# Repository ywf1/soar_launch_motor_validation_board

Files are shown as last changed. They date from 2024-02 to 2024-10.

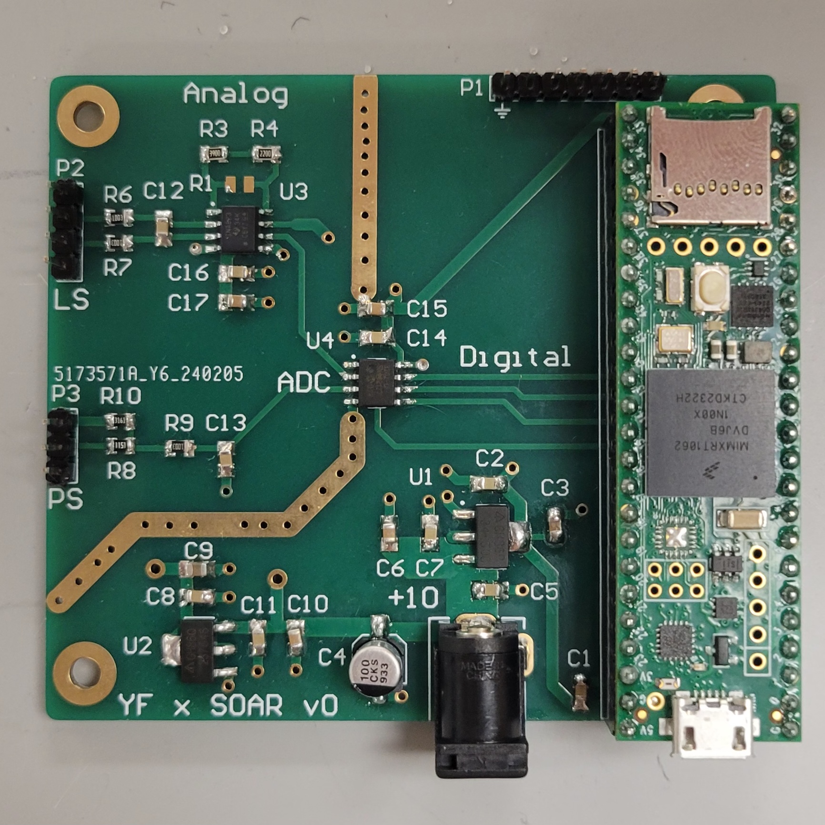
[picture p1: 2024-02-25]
flics/20240222_174141.jpg

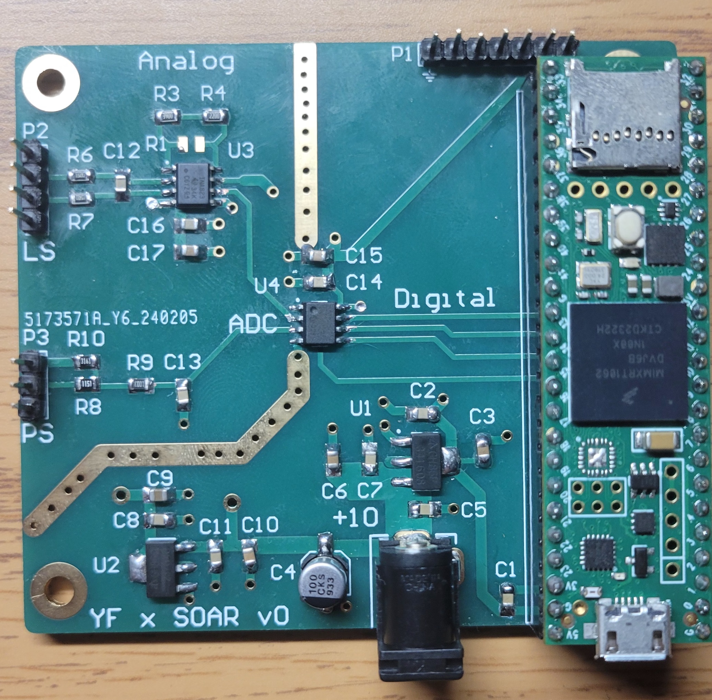
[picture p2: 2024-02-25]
flics/20240224_214641.jpg

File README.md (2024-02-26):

# soar_launch_motor_validation_board
PCB and Arduino Code for a data logging board for collecting data on solid rocket force and pressure output, along with GPIO for triggering ignition and testing

Sensor Inputs:
-  Load Cell
-  Pressure Sensor

[Load Cell](https://www.tgloadcells.com/products/tjh-4a-pancake-load-cell/):
-  +10V excitation
-  20mV @ max Load (1000 N)

[Pressure Sensor](https://www.rocketmotorparts.com/details/p1577809_21906261.aspx):
-  0 - 1600 PSI input
-  .5V - 4.5V voltage output

Board specs:
-  [Teensy 4.1 MCU](https://www.pjrc.com/store/teensy41.html)
-  [INA823 Instrumental Amplifier](https://www.ti.com/product/INA823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)
-  [MCP3202T 12-bit, 2 Channel, 50ksps](https://www.microchip.com/en-us/product/mcp3202)
-  Dual 3.3V, 5V LDO power bus
-  Accessible GPIO
  
Schematic:


Picture:


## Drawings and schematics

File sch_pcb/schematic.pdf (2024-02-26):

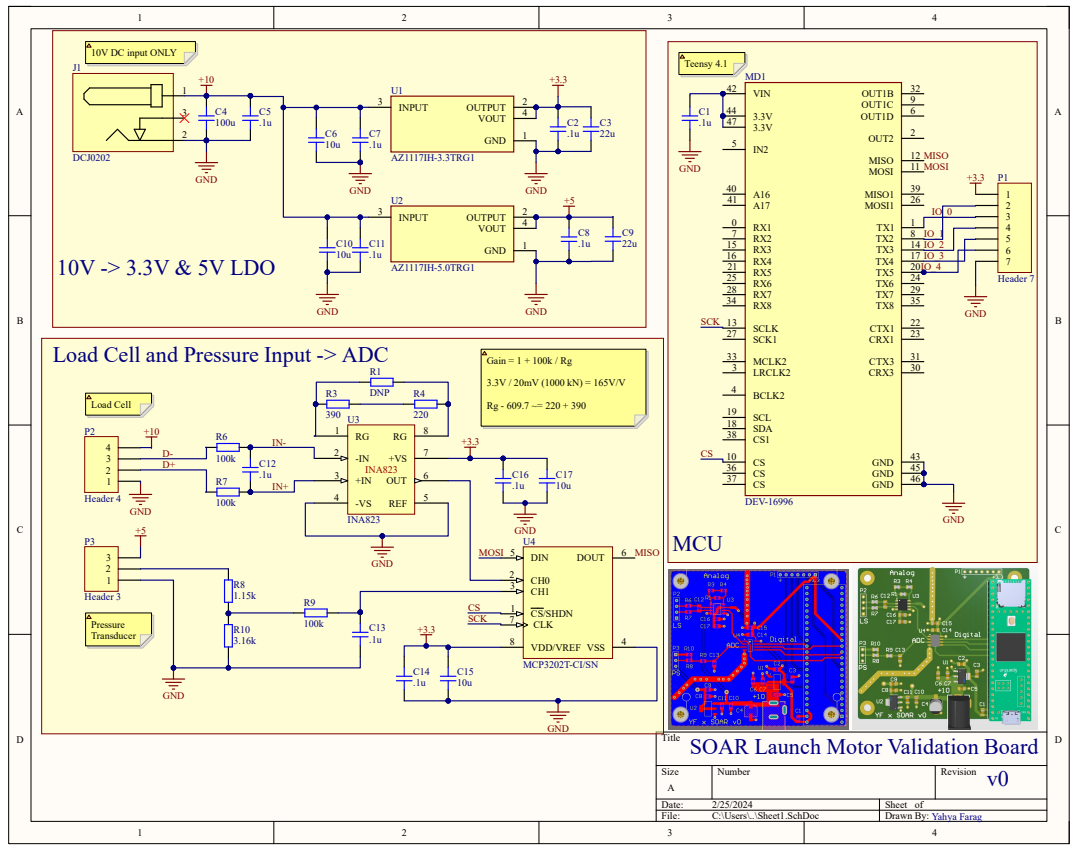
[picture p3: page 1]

Load Cell and Pressure Input -> ADC

Title
SOAR Launch Motor Validation Board

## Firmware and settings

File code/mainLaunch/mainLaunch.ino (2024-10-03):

#include <SPI.h>
#include <MCP3202.h>
#include <SD.h>
//these are dummy values rn
#define relayPin 8
#define beginLaunchPin 17
#define endParsingPin 14
#define LED 33

elapsedMicros timeStamp;

File dataFile;
// Variables will change:
volatile bool startParsing = false;
volatile bool fire = false;
volatile bool launchOver = false;

const double Vdd = 3.3; //Vdd

// Generally, you should use "unsigned long" for variables that hold time
// The value will quickly become too large for an int to store
unsigned long previousMillis = 0;  // will store last time LED was updated

MCP3202 adc = MCP3202(10); //Parameter passed is the CS pin number. Change according to requirement.

int pressureV = 0;
int forceV = 0;

long dummyCounter = 0;

void setup() {
  adc.begin();
  Serial.begin(115200);

  //I/O
  pinMode(relayPin, OUTPUT);
  digitalWrite(relayPin, LOW);
  pinMode(LED, OUTPUT);
  digitalWrite(LED, LOW);

  //begin launch input and interrupt
  pinMode(beginLaunchPin, INPUT_PULLDOWN);
  attachInterrupt(digitalPinToInterrupt(beginLaunchPin), beginLaunch, HIGH);

  //begin stop launch input and interrupt
  pinMode(endParsingPin, INPUT_PULLDOWN);
  attachInterrupt(digitalPinToInterrupt(endParsingPin), endParsing, HIGH);
  
  //SD setup
  if (!SD.begin(BUILTIN_SDCARD)) {
    Serial.println("Card failed, or not present");
    while (1) {
      // No SD card, so don't do anything more - stay stuck here
    }
  }
  dataFile = SD.open("3_31_0.txt", FILE_WRITE);
  if (dataFile) {
      Serial.println("SD Card File Found and Created");
      dataFile.println("Time(us),ForceRaw,PressureRaw,RelayValue");
    } 
}

void loop() {
  if(startParsing && !launchOver){
    if(timeStamp >= 1000000){
      fire = true;
      digitalWrite(relayPin, HIGH);
      if(timeStamp >= 2000000){
        digitalWrite(relayPin,LOW);
        fire = false;
      }
    }
    if (dataFile) {
      //log timestamp, pressure adc reading, and force adc readings
      pressureV = adc.readChannel(0);
      forceV = adc.readChannel(1);
      dataFile.print(timeStamp);
      dataFile.print(",");
      dataFile.print(pressureV);
      dataFile.print(",");
      dataFile.print(forceV);
      dataFile.print(",");
      dataFile.println(fire);
      //Serial.println(dummyCounter);
      //dummyCounter++;
    }
    if(timeStamp >= 20000000){
      startParsing = false;
      launchOver = true;
      dataFile.close();
    }
  } else if(launchOver){
    dataFile.close();
    digitalWrite(LED,HIGH);
    Serial.println("LaunchOver");
    digitalWrite(LED,HIGH);
    delay(500);
    digitalWrite(LED,LOW);
    delay(500);
  } else{
    //Serial.println("Awaiting launch..."); delay(100);
  }
}

void beginLaunch(){
  startParsing = true;
  timeStamp = 0;
  detachInterrupt(digitalPinToInterrupt(beginLaunchPin));
}

void endParsing(){
  if(startParsing){
    startParsing = false;
    launchOver = true;
    dataFile.close();
  }
}

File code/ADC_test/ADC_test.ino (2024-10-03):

#include <SPI.h>
#include <MCP3202.h>

const int ledPin = 33;  // the number of the LED pin

// Variables will change:
int ledState = LOW;  // ledState used to set the LED

// Generally, you should use "unsigned long" for variables that hold time
// The value will quickly become too large for an int to store
unsigned long previousMillis = 0;  // will store last time LED was updated

// constants won't change:
const long interval = 1000;  // interval at which to blink (milliseconds)

float Vdd = 3.3; //change according to your Vdd value.

MCP3202 adc = MCP3202(10); //Parameter passed is the CS pin number. Change according to requirement.

float channel0 = 0;
float channel1 = 0;
void setup() {
  // put your setup code here, to run once:
  adc.begin();
  Serial.begin(115200);
  pinMode(ledPin, OUTPUT);
}

void loop() {
  // put your main code here, to run repeatedly:
  channel0 = adc.readChannel(0);
  channel1 = adc.readChannel(1);
  //Serial.print(channel0);
  //Serial.print("channel 0 \t");

  //Serial.println(channel0);

  Serial.println(1.0*channel0*Vdd/4096.0);
  Serial.println(1.0*channel1*Vdd/4096.0);


  unsigned long currentMillis = millis();

  if (currentMillis - previousMillis >= interval) {
    // save the last time you blinked the LED
    previousMillis = currentMillis;

    // if the LED is off turn it on and vice-versa:
    if (ledState == LOW) {
      ledState = HIGH;
    } else {
      ledState = LOW;
    }

    // set the LED with the ledState of the variable:
    digitalWrite(ledPin, ledState);
  }
  delay(10);
}

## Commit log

2024-02-12 Altium Files and pdf schematic
    [PCB1.PcbDoc, SOAR_Motor_Validation_Board.PrjPcb, Sheet1.SchDoc]
2024-10-03 arduino code from 2023-24 year
